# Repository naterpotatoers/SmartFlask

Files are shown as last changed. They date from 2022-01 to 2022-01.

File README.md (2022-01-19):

# SmartFlask
For CruzHacks 2022
By Adrian, Adrien, Nate, Weston
<br/>


An IoT bottle that tracks water consumption. Winner of Best Health Hack, MLH's Best Hardware Hack, and QB3's Best Big Data for the Improvement of Health Care Winner at CruzHacks 2022.
<br/>
[Plan of Reference Document](https://docs.google.com/presentation/d/102n18cPRJnqRSowYpp3QLn0Yix3CWpKABw2xC8X9vEw/edit?usp=sharing)
<br/>
[YouTube Video](https://www.youtube.com/watch?v=BKwhg2OnEeA)

# Inspiration
Wanted a way to monitor how much water we consumed throughout our day and over a month period

# What it does
The SmartFlask measures the amount of water in a water bottle and the amount you've consumed over time. It then transmits a radio signal to a receiver and posts it to a web server where the data is saved to a database for you to view it later in the web browser.

# How we built it
Hardware
3D Model

We built this device using a Heltec ESP32 for the main computation, a LoRa module for transmission of data, an ultrasonic sensor for monitoring the distance of the water in the bottle, an IMU to measure the movement of the water bottle, a GPS module so you don't lose your water bottle and a power system. On the software side we built out the webserver using Node.js and MySQL. We create the user interface using Next.js and vanilla CSS.

# Challenges we ran into
On the hardware side we ran into problems parsing data, power management, water/IMU calculation, and creating the 3D printed lid. On the software side we had trouble building out the user interface as this was something none of us were really experienced in. We also tried deploying our application using Google's Kubernete Engine service with no luck. We also attempted to automate the deployment to Kubernetes using GitHub Actions as apart of our CI/CD build pipeline with no luck.

# Accomplishments that we're proud of
Successfully calculating the amount of water in the bottle using a depth sensor. 3D printing the housing unit for the water bottle. Creating unique SQL queries that were a bit complex for our leaderboard feature.

# What we learned
The difficulty of working with new software tools that we are unfamiliar with. How to work together as a team and find the necessary tasks to build and execute a full system of hardware, embedded, and web development. The importance of setting realistic goals.

# What's next for SmartFlask
We plan to continue working on this project and redesigning the top as we did not have time to 3D print the design we wanted. Further refining the user interface and building out more useful graphs.

Bottle

Built With
c++
css
express.js
google
mysql
nextjs
node.js
platformio
typescript
<br/>
[Full Project on Devpost](https://devpost.com/software/smartflask)

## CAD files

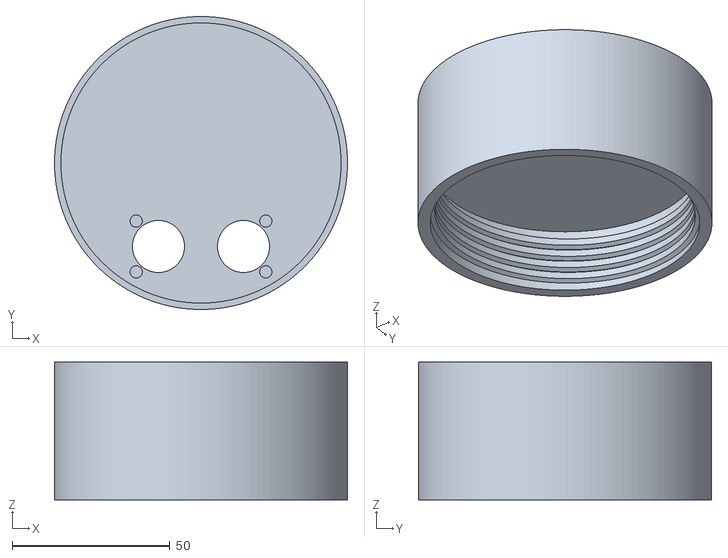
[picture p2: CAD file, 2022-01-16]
cad/Lid - Lid Body.stl
93.0 x 93.0 x 43.7

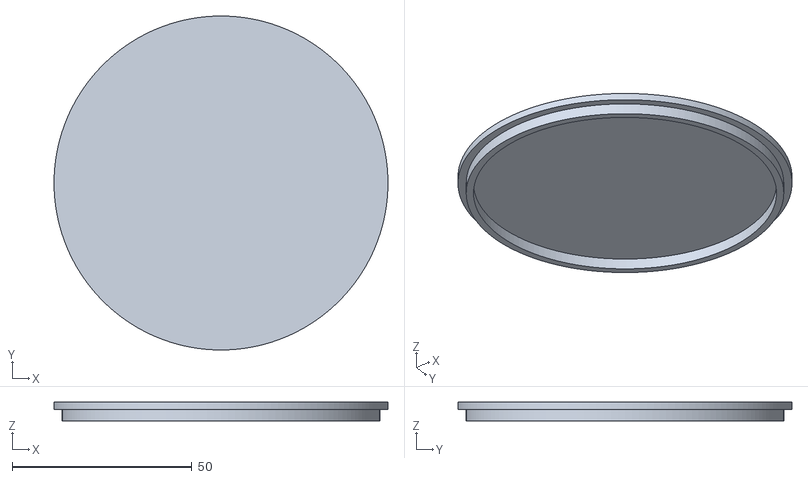
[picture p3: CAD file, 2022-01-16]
cad/Lid - Lid Housing Cap.stl
93.0 x 93.0 x 5.21

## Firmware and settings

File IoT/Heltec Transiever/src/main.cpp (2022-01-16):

#include <math.h>
#include <Arduino.h>
#include <algorithm>
#include <bits/stdc++.h>

// LoRa and Heltec
#include <heltec.h>
#include <LoRa.h>

// GPS Module
#include <TinyGPS++.h>
#include <SoftwareSerial.h>

// Ultrasonic Sensor
#include "E:\SmartFlask\IoT\Heltec Transiever\lib\Ultrasonic_sensor.hpp"

// MPU 6050
#include <Adafruit_MPU6050.h>
#include <Adafruit_Sensor.h>
#include <Wire.h>

const long frequency = 915E6; // LoRa Frequency
float bottle_depth = 27;
float water_height = 0.0;
float bottle_radius = 7;
float volume_amount = 0.0;
float current_water_amount = 0.0;
float max_water = 3800.0;
float amount_consumed = 0.0;
String flask_name = "FlaskyWasky";
String gps_string;

UltrasonicSensor us_sensor(12, 13);

// GPS
double Lon, Lat;
TinyGPSPlus gps;
static const int RXPin = 17, TXPin = 2;
static const uint32_t GPSBaud = 9600;

Adafruit_MPU6050 mpu;
sensors_event_t a, g, temp;

String GetGPS()
{
  while (Serial2.available())
  {
    gps.encode(Serial2.read());
    if (gps.location.isUpdated())
    {

      Lat = gps.location.lat();
      Lon = gps.location.lng();
      gps_string = (String)Lat + "," + (String)Lon;
      // delay(3000);
    }
  }
  return gps_string;
}

float GetAccel()
{
  // Under Construction
  Serial.print(a.acceleration.x, 1);
  Serial.print(a.acceleration.y, 1);
  return 0.0;
}

float GetWaterTemp()
{
  return temp.temperature;
}

float GetCurrentDistance()
{
  return us_sensor.GetDistanceCM();
}

float AmountOfWater()
{
  water_height = bottle_depth - GetCurrentDistance();
  volume_amount = M_PI * (bottle_radius * bottle_radius) * water_height;
  if (volume_amount <= 0)
  {
    volume_amount = 0;
  }
  return volume_amount;
}

float AmountDrank()
{
  amount_consumed = max_water - AmountOfWater();
  if (amount_consumed <= 0)
  {
    amount_consumed = 0;
  }
  return amount_consumed;
}

void GetSensors()
{
  // UL sensor data output
  us_sensor.SenseDistance();
  us_sensor.PrintData();
  Serial.println("Amount of Water: " + String(AmountOfWater()) + "mL");
  Serial.println("Amount Consumed: " + String(AmountDrank()) + "mL\n");
  Serial.print("\nLatitude: " + (String)Lat + "\nLongitude: " + (String)Lon + "\n");
  // GPS
  // GetGPS();

  // MPU
}

void CompileSensors()
{
  // time_tilted, GPS_location;
  GetSensors();
  // need to do: Compute mpu angle
  LoRa.println(AmountOfWater());
  LoRa.println(GetWaterTemp());
  LoRa.println(AmountDrank());
  LoRa.println(5); // time_tilted IMU
  LoRa.println(GetGPS());
  LoRa.println(flask_name);
}

void SendLoRaPacket()
{
  LoRa.beginPacket();
  CompileSensors();
  LoRa.endPacket();
}

void setup()
{
  Serial.begin(9600);
  Serial2.begin(GPSBaud, SERIAL_8N1, RXPin, TXPin);

  // if (!mpu.begin())
  // {
  //   Serial.println("Failed to find MPU6050 chip");
  //   while (1)
  //   {
  //     delay(10);
  //   }
  // }

  Serial.println("MPU6050 Found!");

  us_sensor.SetUp();
  mpu.getEvent(&a, &g, &temp);

  Heltec.begin(true /*DisplayEnable Enable*/, false /*LoRa Enable*/, false /*Serial Enable*/);

  Serial.println("LoRa Sender starting...");
  if (!LoRa.begin(915E6, 1))
  { // Set frequency to 433, 868 or 915MHz
    Serial.println("Could not find a valid LoRa transceiver, check pins used and wiring!");
  }
}

void loop()
{
  SendLoRaPacket();
  delay(3000);
}

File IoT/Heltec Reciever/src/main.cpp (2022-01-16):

#include "heltec.h"
#include "LoRa.h"
#include "HTTPClient.h"
#include "WiFiMulti.h"
#include "ArduinoJson.h"
#include "Adafruit_Sensor.h"

const char *AP_SSID = "kingdom2";
const char *AP_PWD = "22039622";

String Packet;
float total_water, water_temp, water_consumed, time_tilted, GPS_location;
char flask_name[100];


WiFiMulti wifiMulti;

void LoraRecieve()
{
  // try to parse packet
  // int packetSize = LoRa.parsePacket();

  if (LoRa.available())
  {
    Serial.println("Packet Received: ");
    Packet = LoRa.readString();
  }

  Serial.println(Packet);
  sscanf(Packet.c_str(), "%f\n%f\n%f\n%f\n%f\n%[^&]\n", &total_water, &water_temp, &water_consumed, &time_tilted, &GPS_location, flask_name);
  delay(10000);
}

void postDataToServer()
{

  Serial.println("Posting JSON data to server...");
  // Block until we are able to connect to the WiFi access point
  if (wifiMulti.run() == WL_CONNECTED)
  {

    HTTPClient http;
    http.begin("http://20.69.111.104:5000/iot");
    http.addHeader("Content-Type", "application/json");

    StaticJsonDocument<200> doc;
    // Add values in the document

    // doc["name"] = "ESP32";
    // doc["temperature"] = temperature;
    // doc["humidity"] = humidity;
    // doc["longitude"] = longitude;
    // doc["latitude"] = latitude;
    // doc["smoke"] = smoke;

    doc["water_level"] = total_water;
    doc["water_temperature"] = water_temp;
    doc["water_consumed"] = water_consumed;
    doc["time_tilted"] = time_tilted;
    doc["flask_gps"] = GPS_location;
    doc["flask_name"] = flask_name;

    String requestBody;
    serializeJson(doc, requestBody);

    int httpResponseCode = http.POST(requestBody);

    if (httpResponseCode > 0)
    {

      String response = http.getString();

      Serial.println(httpResponseCode);
      Serial.println(response);
    }
    else
    {

      // Serial.printf("Error occurred while sending HTTP POST: %s\n", http.errorToString(statusCode).c_str());
    }
  }
}

void setup()
{
  Serial.begin(9600);
  while (!Serial);

  Heltec.begin(true /*DisplayEnable Enable*/, false /*LoRa Enable*/, false /*Serial Enable*/);
  Serial.println("LoRa Receiver");

  if (!LoRa.begin(915E6, 1))
  {
    Serial.println("Starting LoRa failed!");
    while (1);
  }

  wifiMulti.addAP(AP_SSID, AP_PWD);
}

void loop()
{
  LoraRecieve();
  postDataToServer();
}

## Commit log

2022-01-15 Ultrasonic sensor class and implementation
2022-01-16 working ultrasonic
2022-01-16 switches frontend to nextjs
2022-01-16 working ultrasonic sensor measuring water amount in mL and water consumed
2022-01-16 fixed a few things
    [main.cpp]
2022-01-16 Add CAD models
    [Lid - Lid Body.stl, Lid - Lid Housing Cap.stl]
2022-01-16 Ultrasonic sensor pins updated
